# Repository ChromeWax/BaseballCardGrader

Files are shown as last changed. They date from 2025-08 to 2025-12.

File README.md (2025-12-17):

# Baseball Card Grader

Identify and detect defects on a card's surface. The project is a combination of a physical device and a mobile app. The physical device is a box that contains four lights and an ESP32. The user can place a card into the box, connect the box to the app via Bluetooth, and then evaluate the image on the app.

The general process involves taking four images, each with a different lighting position, and then compositing those four images into a normal map that represents 3D detail. This normal map is then used to run our model on the annotated image.

https://github.com/user-attachments/assets/8a07d7a1-3c0c-4498-98e6-cceb2a37a0a0

## Mobile App
This app was built with MAUI Blazor Hybrid with .NET 9. Visit the path `BaseballCardGrader/Apps` for the relevant code to this section. 

### Image Processor Project
This project is responsible for compositing the four images into a normal map and inferencing the ONNX model for annotations. The SkiaSharp library was the only one found to be performant on mobile.

#### Helpful Guides
The following guides help create a normal map and run ONNX inference.
- [ONNX Inference](https://onnxruntime.ai/docs/tutorials/csharp/fasterrcnn_csharp.html)
- [Normal Map Process](http://zarria.net/nrmphoto/nrmphoto.html)

### MAUI Blazor Hybrid App
This project utilizes the Image Processor project for image processing. This will connect to the ESP32 device, take four images with the smartphone's camera, composite those images into a normal map, and then run the ONNX model on them. This project uses the MAUI Blazor Hybrid template for cross-platform support.

#### Helpful Guides
The following guide helps connect the mobile app to the ESP32 via Bluetooth.
- [MAUI Bluetooth](https://github.com/dotnet-bluetooth-le/dotnet-bluetooth-le)

### Requirements
- .NET 9 SDK
- MAUI workloads

#### Helpful Guides
The following guide is practical for installing MAUI.
- [Installing Maui](https://learn.microsoft.com/en-us/dotnet/maui/get-started/installation?view=net-maui-9.0&tabs=visual-studio)

## ONNX Model
An ONNX model is a machine learning model saved in the Open Neural Network Exchange format, which allows different frameworks to share and run it. We use it for use in the [mobile app](#maui-blazor-hybrid-app). Visit the path `BaseballCardGrader/Trainer` for the code relevant to this section.

### Annotating Images
The model assumes only normal images are used for training. These normal images can be extracted from the mobile app. They can then be annotated with a program like LabelMe. If using LabelMe, ensure "Save With Image Data" is not toggled on. 

Newly annotated images can be stored in `BaseballCardGrader/Trainer/dataset`.

#### Links
Links to install LabelMe.
- [LabelMe GitHub](https://github.com/wkentaro/labelme)

### Training The Model
In the `BaseballCardGrader/Trainer` directory, run the following command.
```
docker compose up
```
This will create a PyTorch container with CUDA support, copy the relevant Python files over, install any dependencies, map the dataset and checkpoint folders to the container, run the script to create the model, and then export the script to the ONNX format.

The ONNX model will be stored in the path `BaseballCardGrader/Trainer/checkpoint` after training is complete.

#### Requirements:
- Nvidia GPU that supports CUDA
- Docker Desktop
- Windows 11 with WSL2 enabled

### Helpful Guides
The following guides are helpful for training and exporting the model.
- [Train Model](https://christianjmills.com/posts/pytorch-train-mask-rcnn-tutorial/)
- [Export To ONNX](https://christianjmills.com/posts/pytorch-train-mask-rcnn-tutorial/onnx-export/)

## Box
### 3D Print
The files in `BaseballCardGrader/Device/cad` can be used to 3D print the box.

#### Caveats
- There is no easy way to attach the lid to the box. An easy solution is to cut the socket on the right side of the box in half. That way, the lid sits on top of it.
- The indent in the middle of the box is a design flaw. The "Box Fix" can be used to fill in the indent.

### ESP32
An ESP32 is a low-cost, low-power microcontroller with built-in Wi-Fi and Bluetooth capabilities. For our case, we use one to handle the LED lights and connect to the mobile app. Visit the Path: `BaseballCardGrader/Device/esp32` for the code relevant to this section. 

#### Components
circuit_image

The following components were used.
- Seeed Studio XIAO ESP32-C3
- 4 White 6500k LEDS
- 1 Button
- Battery (Optional)
  
##### Buy links
- [ESP32 Amazon Link](https://www.amazon.com/dp/B0B94JZ2YF?ref=ppx_yo2ov_dt_b_fed_asin_title&th=1)
- [White 6500k LEDS Amazon Link](https://www.amazon.com/dp/B01DBZICDC?ref=ppx_yo2ov_dt_b_fed_asin_title&th=1)
- [Button Amazon Link](https://www.amazon.com/DIYables-Button-Arduino-ESP8266-Raspberry/dp/B0BXKN4TY6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)
- [Battery Amazon Link](https://www.amazon.com/dp/B08T6GT7DV?ref=ppx_yo2ov_dt_b_fed_asin_title)

#### Updating Firmware
PlatformIO is used in place of the Arduino IDE for improved version control support. It can be used to upload newer Firmware to the ESP32 device.

##### Helpful Guides
The following guides help you learn PlatformIO and code for ESP32.
- [PlatformIO Tutorial](https://www.youtube.com/watch?v=QMYhVqjBhKQ&t=693s)
- [ESP32 Guide](https://wiki.seeedstudio.com/XIAO_ESP32C3_Getting_Started/)

##### Requirements
- Visual Studio Code
- PlatformIO extension

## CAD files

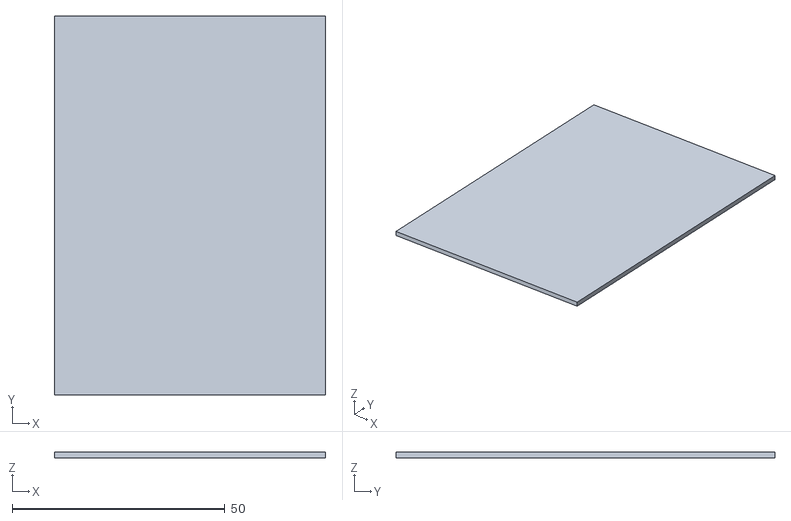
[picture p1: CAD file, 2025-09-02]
BaseballCardGrader/Device/cad/Box Fix.stl
63.7 x 89.0 x 1.30

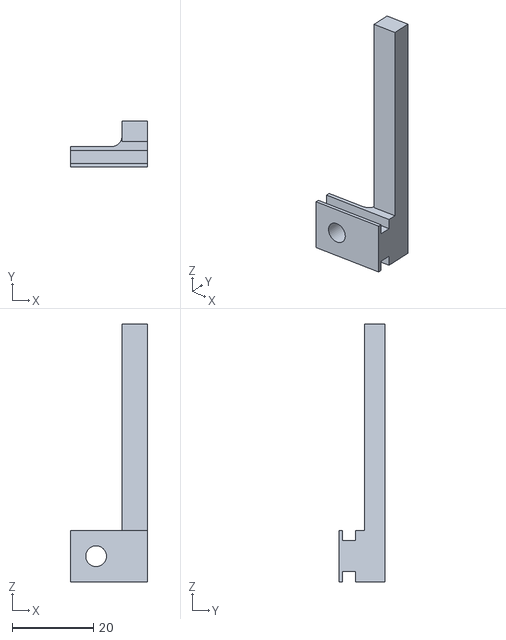
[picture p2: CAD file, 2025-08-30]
BaseballCardGrader/Device/cad/Phone Holder Slide - Side Right.STL
19.1 x 11.4 x 63.5

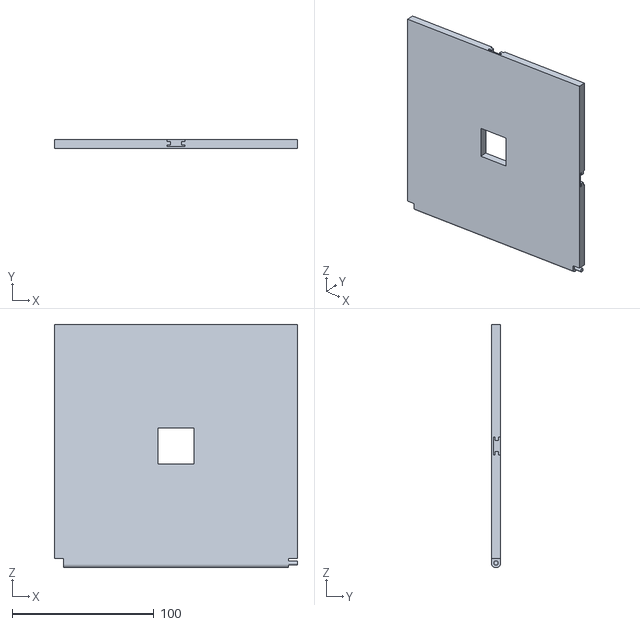
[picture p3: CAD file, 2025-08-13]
BaseballCardGrader/Device/cad/Trap Door Flap.STL
171.4 x 6.35 x 171.4

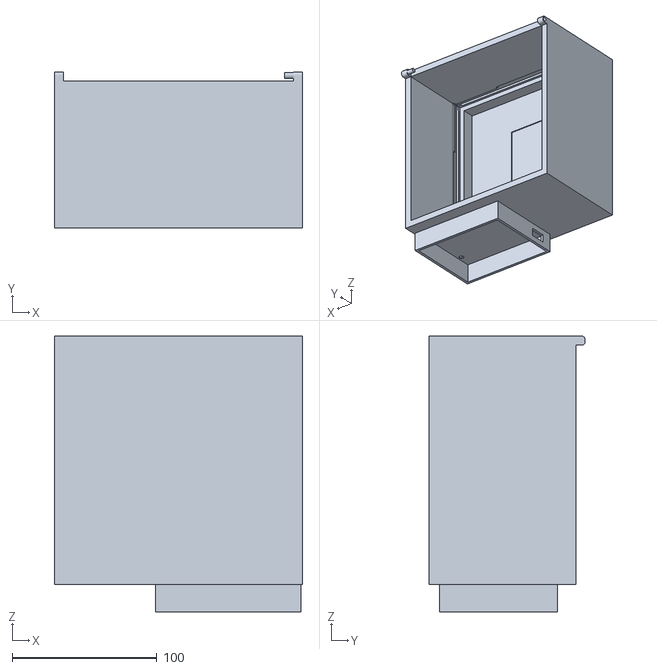
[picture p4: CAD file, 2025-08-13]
BaseballCardGrader/Device/cad/Box.STL
171.4 x 108.0 x 190.5

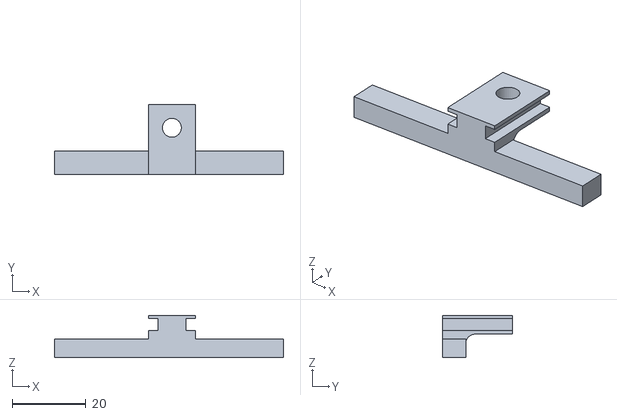
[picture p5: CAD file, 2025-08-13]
BaseballCardGrader/Device/cad/Phone Holder Slide - Side Center.STL
61.9 x 19.1 x 11.4

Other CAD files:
BaseballCardGrader/Device/cad/Phone Holder Slide - Side Left.STL

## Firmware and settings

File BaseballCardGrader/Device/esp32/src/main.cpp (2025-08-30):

#include <Arduino.h>
#include <BLEDevice.h>
#include <BLEUtils.h>
#include <BLEServer.h>

// See the following for generating UUIDs:
// https://www.uuidgenerator.net/
#define DEVICE_NAME         "Baseball Card Grader Device"
#define SERVICE_UUID        "7123acc7-b24d-4eee-9c7f-ee6302637aef"
#define CHARACTERISTIC_UUID "8be0f272-b3be-4351-a3fc-d57341aa628e"

enum class Command {
  None,
  UpOn,
  DownOn,
  LeftOn,
  RightOn,
  ToggleAllOn
};

enum class Notification {
  LedOn,
  LedOff
};

// define led according to pin diagram in article
const int wakePin = D0;
const int upLedPin = D3;
const int downLedPin = D4;
const int leftLedPin = D5;
const int rightLedPin = D6;

const std::map<Command, int> commandToLedPin = {
  { Command::UpOn, upLedPin },
  { Command::DownOn, downLedPin },
  { Command::LeftOn, leftLedPin },
  { Command::RightOn, rightLedPin }
};

const std::vector<Command> pulseCommands = {
  Command::UpOn,
  Command::DownOn,
  Command::LeftOn,
  Command::RightOn
};

const std::map<Notification, std::string> notificationToString = {
  { Notification::LedOn, "LedOn" },
  { Notification::LedOff, "LedOff" }
};

const int oneSecond = 1000;
const int oneMinute = oneSecond * 60;
const int sleepTime = oneMinute * 2;

// function declarations
Command parseCommand(const std::string& value);
void setAllLedsOff();
void setAllLedsOn();
void goToSleep();
bool isPulseCommand(Command cmd);

// global variables
BLEAdvertising *pAdvertising = nullptr;
BLECharacteristic *pCharacteristic = nullptr;
unsigned long lastActivityTime = 0;

// callbacks for connecting and disconnecting BLE clients
class MyServerCallbacks: public BLEServerCallbacks {
    void onConnect(BLEServer* pServer) override {
        lastActivityTime = millis();
    }
    void onDisconnect(BLEServer* pServer) override {
        // Restart advertising so clients can reconnect
        if (pAdvertising) {
            pAdvertising->start();
        }
        lastActivityTime = millis();
    }
};

// callbacks for handling commands
class MyCharacteristicCallbacks: public BLECharacteristicCallbacks {
    void onWrite(BLECharacteristic *pCharacteristic) {
      std::string value = pCharacteristic->getValue();

      if (value.length() > 0) {
        Command command = parseCommand(value);

        if (isPulseCommand(command))
        {
          setAllLedsOff();
          auto entry = commandToLedPin.find(command);
          if (entry != commandToLedPin.end()) {
            digitalWrite(entry->second, HIGH);
            pCharacteristic->setValue(notificationToString.at(Notification::LedOn));
            pCharacteristic->notify();
          }
        }
        else if (command == Command::ToggleAllOn)
        {
          setAllLedsOn();
          pCharacteristic->setValue(notificationToString.at(Notification::LedOn));
          pCharacteristic->notify();
        }
        else if (command == Command::None)
        {
          setAllLedsOff();
          pCharacteristic->setValue(notificationToString.at(Notification::LedOff));
          pCharacteristic->notify();
        }
        lastActivityTime = millis();
      }
    }
};

Command parseCommand(const std::string& value) {
    if (value == "UpOn") return Command::UpOn;
    if (value == "DownOn") return Command::DownOn;
    if (value == "LeftOn") return Command::LeftOn;
    if (value == "RightOn") return Command::RightOn;
    if (value == "ToggleAllOn") return Command::ToggleAllOn;
    return Command::None;
}

void setAllLedsOff() {
  digitalWrite(upLedPin, LOW);
  digitalWrite(downLedPin, LOW);
  digitalWrite(leftLedPin, LOW);
  digitalWrite(rightLedPin, LOW);
}

void setAllLedsOn() {
  digitalWrite(upLedPin, HIGH);
  digitalWrite(downLedPin, HIGH);
  digitalWrite(leftLedPin, HIGH);
  digitalWrite(rightLedPin, HIGH);
}

bool isPulseCommand(Command cmd) {
  return std::find(pulseCommands.begin(), pulseCommands.end(), cmd) != pulseCommands.end();
}

void goToSleep() {
  setAllLedsOff();
  if (pAdvertising) pAdvertising->stop();
  esp_deep_sleep_enable_gpio_wakeup(BIT(wakePin), ESP_GPIO_WAKEUP_GPIO_LOW);
  esp_deep_sleep_start();
}

void setup() {
  Serial.begin(115200);

  // initialize digital pin led as an output
  pinMode(upLedPin, OUTPUT);
  pinMode(downLedPin, OUTPUT);
  pinMode(leftLedPin, OUTPUT);
  pinMode(rightLedPin, OUTPUT);

  // turn off all LEDs initially
  setAllLedsOff();

  BLEDevice::init(DEVICE_NAME);
  BLEServer *pServer = BLEDevice::createServer();
  pServer->setCallbacks(new MyServerCallbacks());

  BLEService *pService = pServer->createService(SERVICE_UUID);
  pCharacteristic = pService->createCharacteristic(
    CHARACTERISTIC_UUID,
    BLECharacteristic::PROPERTY_WRITE |
    BLECharacteristic::PROPERTY_NOTIFY
  );
  pCharacteristic->setCallbacks(new MyCharacteristicCallbacks());
  pService->start();

  pAdvertising = pServer->getAdvertising();
  pAdvertising->addServiceUUID(SERVICE_UUID);
  pAdvertising->start();

  lastActivityTime = millis();
}

void loop() {
  auto elapsedTime = millis() - lastActivityTime;
  if (elapsedTime > sleepTime) {
    goToSleep();
  }

  delay(10);
}

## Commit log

2025-07-21 current state of the MAUI app
2025-08-03 Rename Device Name to "Baseball Card Grader Device"
2025-08-03 Add sleeping and wake button
2025-08-04 Add ServiceUuid to ESP32 when advertising
2025-08-04 Fix typo in esp32 code
    [main.cpp]
2025-08-04 Move esp32 files to esp32 folder
2025-08-04 Scans bluetooth devices
2025-08-04 Now connects to esp32
2025-08-04 Connect to esp32 with maui
2025-08-04 Capitliaze first letter of command in esp32
2025-08-12 ESP32 now sends notifications when led is on to better sync with maui app
2025-08-12 Update ESP32 to send an additional notification when led is off
2025-08-12 Home page can now detect notifications from esp32
2025-08-12 Fix issue where maui app cannot reconnect to esp32
2025-08-13 Uploaded STL files to the Hardware folder
    [Box.STL, Phone Holder Slide - Side Center.STL, Phone Holder Slide - Side Left.STL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]
2025-08-13 Moved files to Device/cad
    [Box.STL, Phone Holder Slide - Side Center.STL, Phone Holder Slide - Side Left.STL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]
2025-08-14 Remove unneeded actions and made app working with esp32
2025-08-14 Refactor to Esp32BluetoothService.cs
2025-08-18 Update Info.plist to include camera permissions for ios
2025-08-29 Add Toggle All Leds On
2025-08-29 Improve bluetooth experience whenever esp32 disconnects unexpectedly
2025-08-29 Remove timer from esp32. Maui app now controls when to turn on leds.
2025-09-01 Update Phone Holder Slide - Side Right.STL
    [Phone Holder Slide - Side Right.STL]
2025-09-02 Create Box Fix.stl
    [Box Fix.stl]
